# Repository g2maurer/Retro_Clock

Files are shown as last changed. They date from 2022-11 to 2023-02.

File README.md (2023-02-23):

# Retro_Clock
This is a highly modified version of TechKiwiGadgets clock found on 

1. Instructables     https://www.instructables.com/ESP32-Pacman-Clock/
2. Makerbot Thingiverse (ESP32 Pacman Clock)    https://www.thingiverse.com/thing:5136672

Modifications:
1. Changed TFT display to an SPI version which has a much improved Touch interface.
2. Added SPIFFS to support files for data and images. This freed up memory and added flexability.
3. Added support for optional RTC (real time clock IC). Improves time keeping accuracy.
4. Added support for LDR (light dependent resistor) so that display is dimmed at night.
5. Added audio amplifier (LM386) and volume control via touch screen.
6. Redesigned user interface (Touch menu) to support added features.
7. Made many changes to firmware to improve speed and readability. 
8. Designed PCB to support above mentioned changes.
9. Redesigned 3D printed parts to support hardware changes.

TFT_eSPI library:
1. The TFT_eSPI library requires it be changed to support each particular build (unusal but that's way way it works).
2. The file User_Setup_Select.h specifies which setup file in the User_Setups directory is to be used.
3. Added to the User_Setups directory is the file Setup_Pacman_Clock.h which contains the specifies the configuration and features (Touch) used by this project.
4. Move the file "Setup_Pacman_Clock.h" into directory   ...Arduino/libraries/TFT_eSPI/User_Setups
5. Move the file "User_Setup_Select.h" into the directory    ...Arduino/libraries/TFT_eSPI   (replaces the existing User_Setup_Select.h file). 

Tools:
1. Arduino IDE 1.8.19, Board: DOIT ESP32 DEVKIT V1
2. Initialize SPIFFS using Arduino IDE  "Tools/ESP32 Sketch Data Upload" (which will initializee SPIFFS and upload all the files from the Data directory).
3. Creality Slicer, PLA, 0.2mm, no supports.

Additional Notes:
1. 	Arduino Sketch (IDE) Version 1.8.19
2.	Board Manager -> esp32 by Espressif Systems Version 1.0.6
3.	Libraries used:

		TFT_eSPI at version 2.5.0
		RTClib at version 2.1.1
		Wire at version 1.0.1
		SPIFFS at version 1.0
		FS at version 1.0
		XT_DAC_Audio
		Time at version 1.6.1
		Adafruit_BusIO at version 1.14.1
4.	TFT_eSPI setup file contains (see TFT_eSPI folder in Arduino/libraries):

		#define USER_SETUP_ID 900
		#define ILI9341_DRIVER
		#define TFT_MISO	19
		#define TFT_MOSI	23
		#define TFT_SCLK	18
		#define TFT_CS		15
		#define TFT_DC		4
		#define TFT_RST		2

		#define TOUCH_CS	5		// Required to enable Touch, getTouch()

		#define LOAD_GLCD
		#define LOAD_FONT2
		#define LOAD_FONT4
		#define LOAD FONT6
		#define LOAD_FONT7
		#define LOAD_FONT8
		#define LOAD_GFXFF
		#define SMOOTH_FONT

		#define SPI_FREQUENCY 27000000					// 27 MHz
		#define SPI_READ_FREQUENCY 20000000				// 20 MHz
		#define SPI_TOUCH_FREQUENCY 2500000				// 2.5 MHz

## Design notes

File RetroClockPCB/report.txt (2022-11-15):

Plot file "C:\Users\Gerald\Documents\KiCad Projects\PacmanClock_ESP32_SPI_v1_1\PacmanClock_ESP32_SPI_v1_1-F_Cu.gbr" created.
Plot file "C:\Users\Gerald\Documents\KiCad Projects\PacmanClock_ESP32_SPI_v1_1\PacmanClock_ESP32_SPI_v1_1-B_Cu.gbr" created.
Plot file "C:\Users\Gerald\Documents\KiCad Projects\PacmanClock_ESP32_SPI_v1_1\PacmanClock_ESP32_SPI_v1_1-Edge_Cuts.gbr" created.
Create Gerber job file "C:\Users\Gerald\Documents\KiCad Projects\PacmanClock_ESP32_SPI_v1_1\PacmanClock_ESP32_SPI_v1_1-job.gbrjob"

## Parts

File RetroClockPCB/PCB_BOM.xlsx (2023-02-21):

Source: | C:\Users\gmaur\Documents\KiCad Projects\PacmanClock_ESP32_SPI_v1_3\PacmanClock_ESP32_SPI_v1_3.sch
Date: | 2023-02-21 08:52
Tool: | Eeschema (5.1.10)-1
Component Count: | 39
Ref | Value | Footprint | Notes | Datasheet | Manufacturer | Vendor
BT1 | LIR2032 | ESP32-footprints-Lib:BatteryHolder_Keystone_103_1x20mm_gm | LIR2032 3.7V Rechargable Battery | ~
C1 | 100nF | Capacitor_SMD:C_0805_2012Metric_Pad1.18x1.45mm_HandSolder |  | ~
C2 | 1uF | Capacitor_SMD:C_0805_2012Metric_Pad1.18x1.45mm_HandSolder |  | ~
C3 | 1000uF |  |  | ~
C4 | 1uF | Capacitor_SMD:C_0805_2012Metric_Pad1.18x1.45mm_HandSolder |  | ~
C5 | 10uF |  |  | ~
C6 | 47nF | Capacitor_SMD:C_0805_2012Metric_Pad1.18x1.45mm_HandSolder |  | ~
C7 | 479uF |  |  | ~
C8 | 100nF | Capacitor_SMD:C_0805_2012Metric_Pad1.18x1.45mm_HandSolder |  | ~
D1 | 1N4148W | Diode_SMD:D_SOD-123 |  | https://www.vishay.com/docs/85748/1n4148w.pdf
H1 | MountingHole | MountingHole:MountingHole_2.7mm_M2.5_DIN965 |  | ~
H2 | MountingHole | MountingHole:MountingHole_2.7mm_M2.5_DIN965 |  | ~
H3 | MountingHole | MountingHole:MountingHole_2.7mm_M2.5_DIN965 |  | ~
H4 | MountingHole | MountingHole:MountingHole_2.7mm_M2.5_DIN965 |  | ~
H5 | MountingHole | MountingHole:MountingHole_2.7mm_M2.5_DIN965 |  | ~
H6 | MountingHole | MountingHole:MountingHole_2.7mm_M2.5_DIN965 |  | ~
H7 | MountingHole | MountingHole:MountingHole_2.7mm_M2.5_DIN965 |  | ~
H8 | MountingHole | MountingHole:MountingHole_2.7mm_M2.5_DIN965 |  | ~
J1 | TFT | Connector_PinSocket_2.54mm:PinSocket_1x14_P2.54mm_Vertical |  | ~
J2 | Power | Connector_JST:JST_XH_B4B-XH-A_1x04_P2.50mm_Vertical |  | ~
J3 | Speaker | Connector_JST:JST_XH_B2B-XH-A_1x02_P2.50mm_Vertical |  | ~
J4 | LDR | Connector_JST:JST_XH_B2B-XH-A_1x02_P2.50mm_Vertical |  | ~
Q1 | 2N7000 | Package_TO_SOT_THT:TO-92 |  | ~
R1 | 20k | Resistor_SMD:R_0805_2012Metric_Pad1.20x1.40mm_HandSolder |  | ~
R2 | 0 | Resistor_SMD:R_0805_2012Metric_Pad1.20x1.40mm_HandSolder | Only install if not supporting LDR | ~
R3 | 1k | Resistor_SMD:R_0805_2012Metric_Pad1.20x1.40mm_HandSolder |  | ~
R4 | 10k | Resistor_SMD:R_0805_2012Metric_Pad1.20x1.40mm_HandSolder |  | ~
R5 | 10 | Resistor_SMD:R_0805_2012Metric_Pad1.20x1.40mm_HandSolder |  | ~
R6 | 4.7k | Resistor_SMD:R_0805_2012Metric_Pad1.20x1.40mm_HandSolder |  | ~
R7 | 10k | Resistor_SMD:R_0805_2012Metric_Pad1.20x1.40mm_HandSolder |  | ~
R8 | 10k | Resistor_SMD:R_0805_2012Metric_Pad1.20x1.40mm_HandSolder |  | ~
R9 | 4.7k | Resistor_SMD:R_0805_2012Metric_Pad1.20x1.40mm_HandSolder |  | ~
R10 | 10k | Resistor_SMD:R_0805_2012Metric_Pad1.20x1.40mm_HandSolder |  | ~
R11 | 4.7k | Resistor_SMD:R_0805_2012Metric_Pad1.20x1.40mm_HandSolder |  | ~
R12 | 200 | Resistor_SMD:R_0805_2012Metric_Pad1.20x1.40mm_HandSolder |  | ~
SW1 | Recal Touch | Tactile-switch:FSM2JRT_gm |  | ~
U1 | LM386 | Package_DIP:DIP-8_W7.62mm_LongPads |  | http://www.ti.com/lit/ds/symlink/lm386.pdf
U2 | ESP-WROOM-32S | ESP32-Footprints:ESP-WROOM-32S
U3 | DS3231M | Package_SO:SOIC-16W_7.5x10.3mm_P1.27mm |  | http://datasheets.maximintegrated.com/en/ds/DS3231.pdf
LDR | 5k | Light dependent resistor | Connected to J4
Speaker | 8 | 8 ohm speaker, 40mm | Connected to J3
TFT |  | 2.8 inch TFT with Touch, SPI interface | Connected to J1

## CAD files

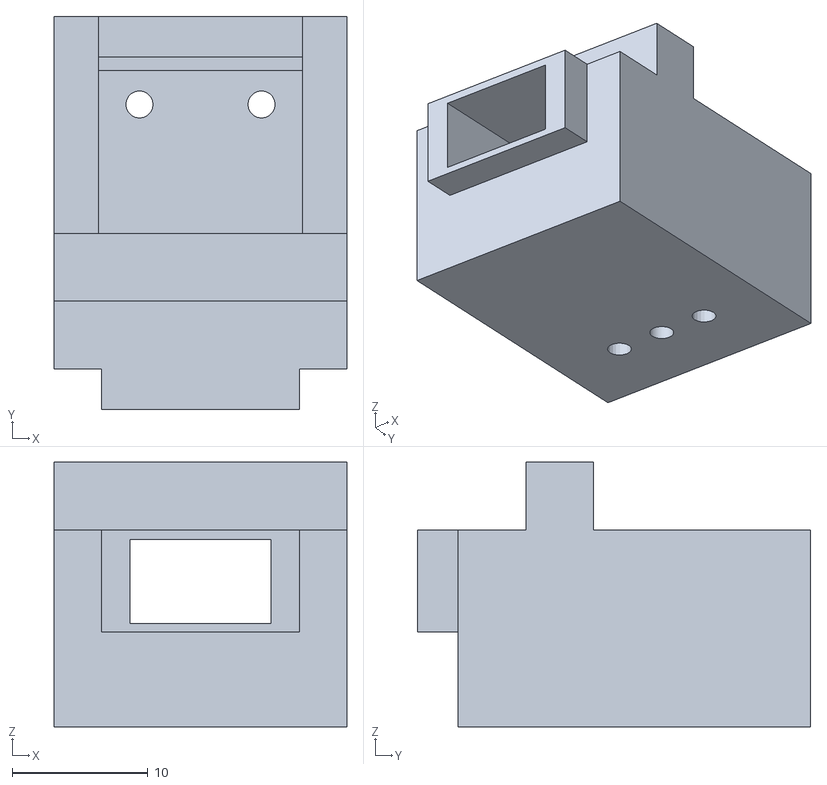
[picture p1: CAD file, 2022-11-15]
RetroClock_Case/MicroUSB2.stl
21.6 x 29.0 x 19.5

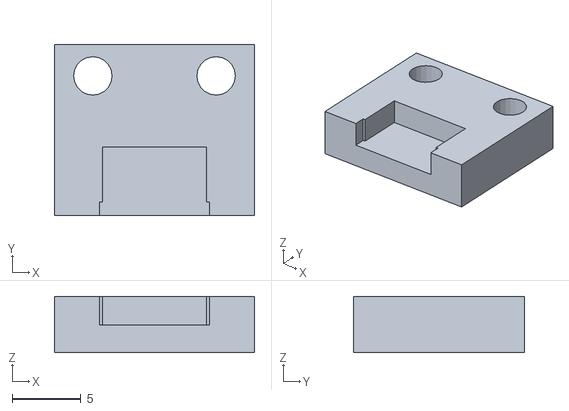
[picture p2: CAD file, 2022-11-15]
RetroClock_Case/USB_Lockdown.stl
14.6 x 12.5 x 4.10

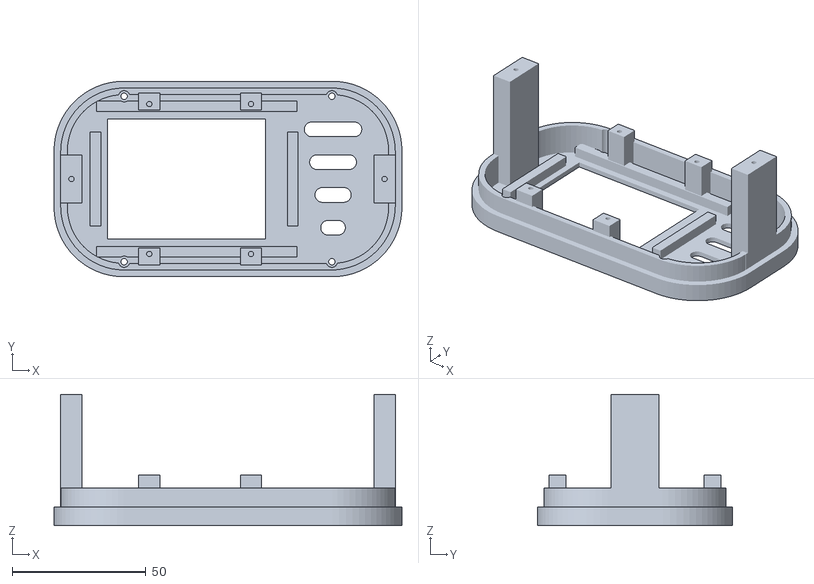
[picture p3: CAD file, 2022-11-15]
RetroClock_Case/ClockBezel.stl
130.0 x 73.0 x 49.0

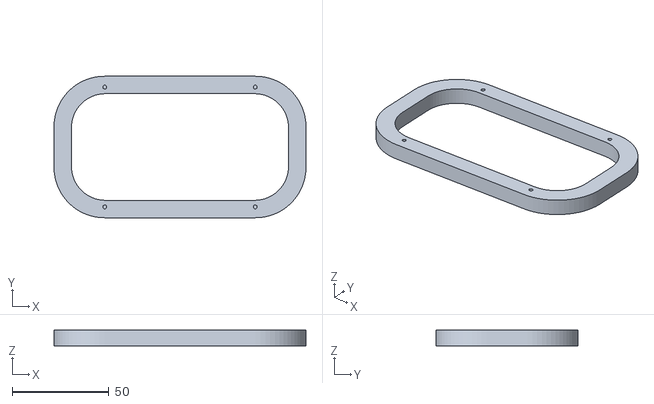
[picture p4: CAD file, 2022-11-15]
RetroClock_Case/BezelTrim.stl
130.0 x 73.0 x 8.00

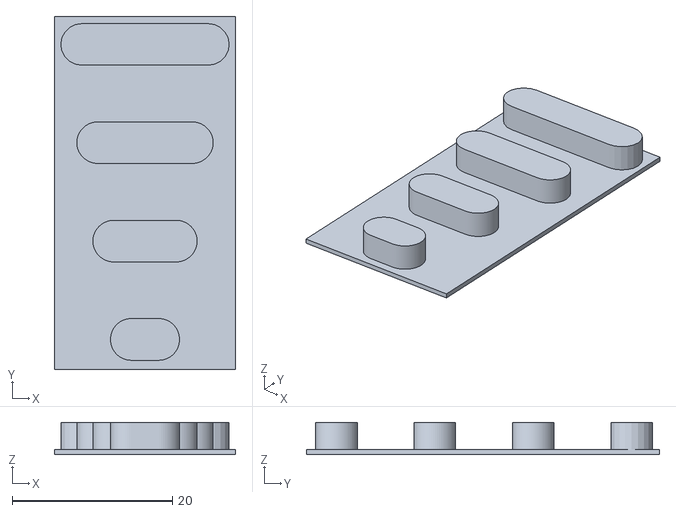
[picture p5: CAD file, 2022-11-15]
RetroClock_Case/BezelDecal.stl
22.6 x 44.0 x 4.00

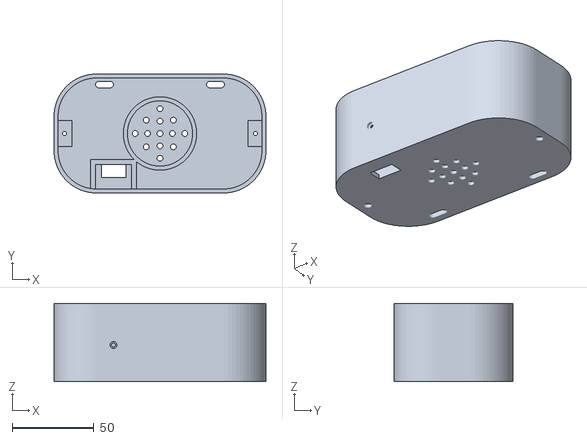
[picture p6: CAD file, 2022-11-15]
RetroClock_Case/ClockCase.stl
130.0 x 73.0 x 48.0

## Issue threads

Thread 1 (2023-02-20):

List of library used

Express1, 2023-02-20:
Can you please post the list of libraries/versions used to compile the project?

morganflint, 2023-02-21:
In my case, I followed the instructions [here](https://www.instructables.com/ESP32-Pacman-Clock/) for the parallel display software, step 6.1 (search "_Loading the correct Correct Libraries for the project!!_" ). Then, for g2maurer's SPI display software, followed the instructions in the readme.md of this repository, points 4 and 5 in the _TFT_eSPI_ library section.

g2maurer, 2023-02-24:
See github for update.

On Tue, Feb 21, 2023 at 3:29 AM morganflint ***@***.***>
wrote:

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

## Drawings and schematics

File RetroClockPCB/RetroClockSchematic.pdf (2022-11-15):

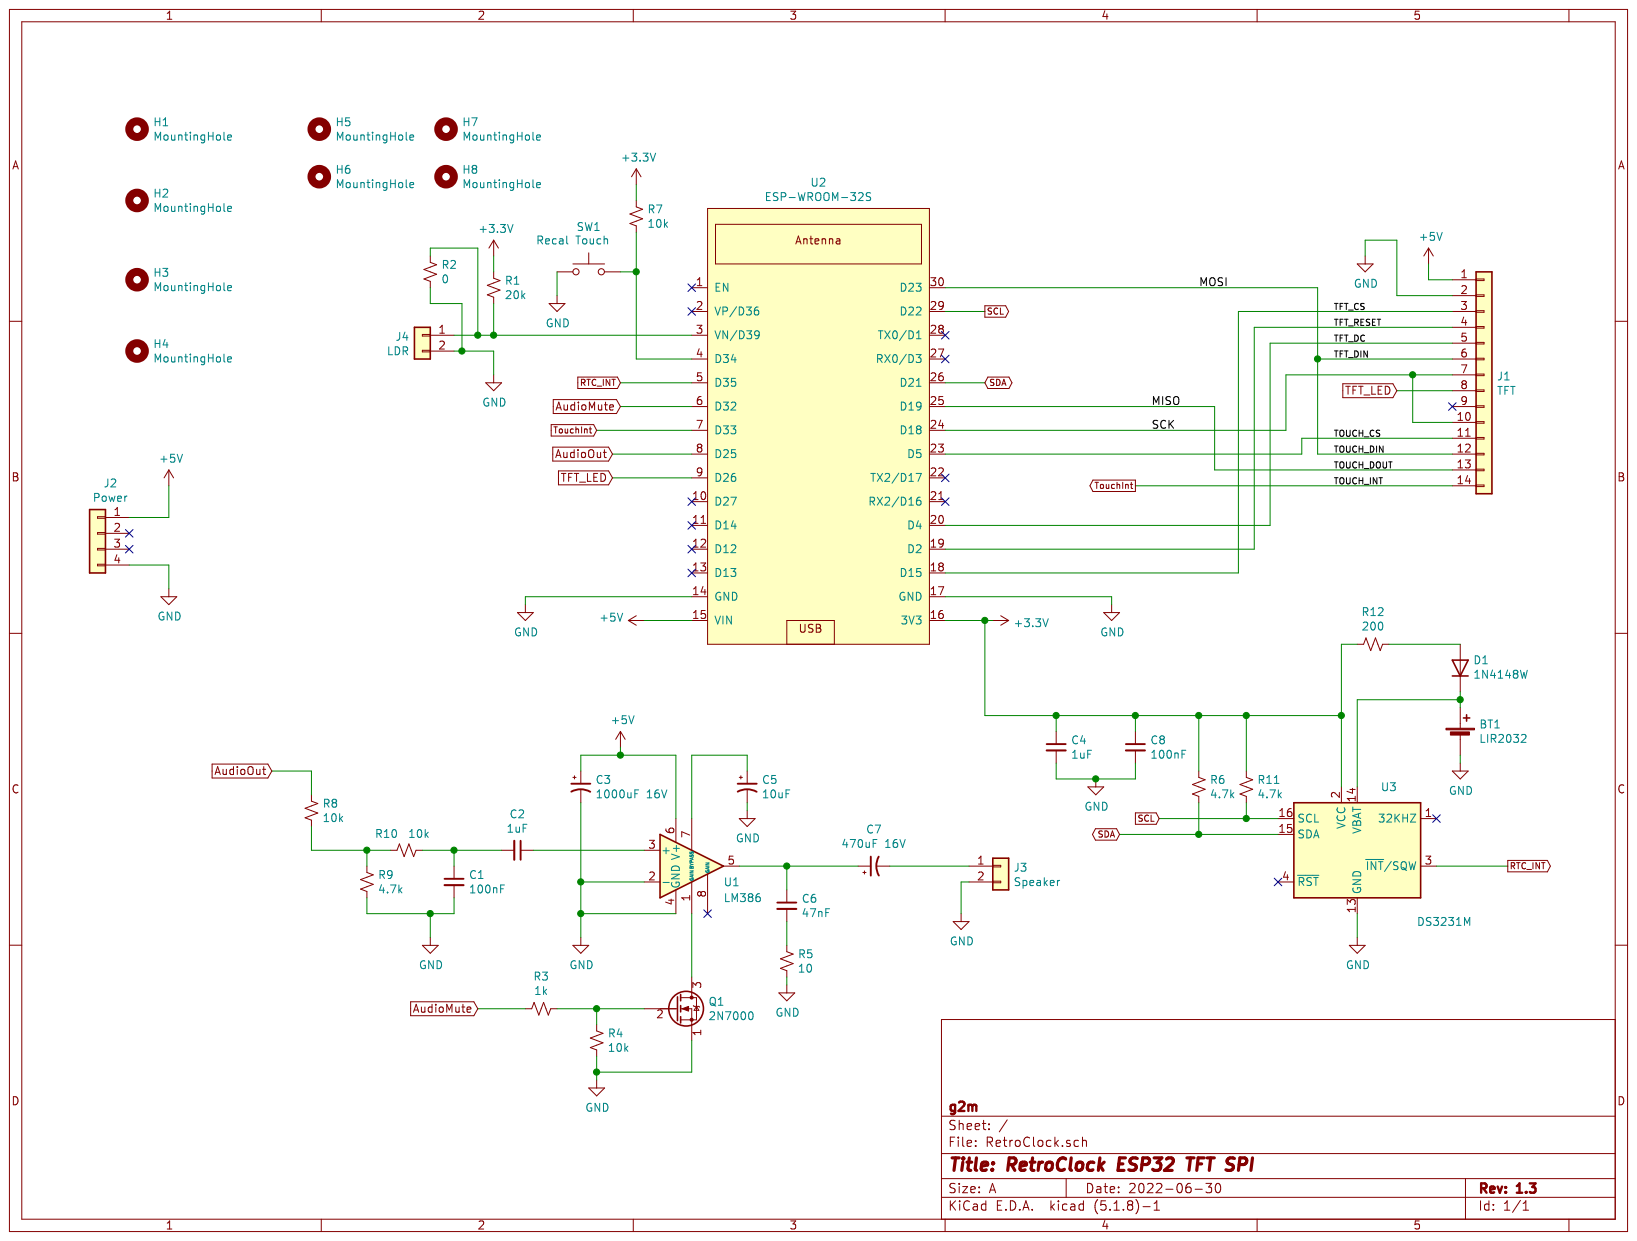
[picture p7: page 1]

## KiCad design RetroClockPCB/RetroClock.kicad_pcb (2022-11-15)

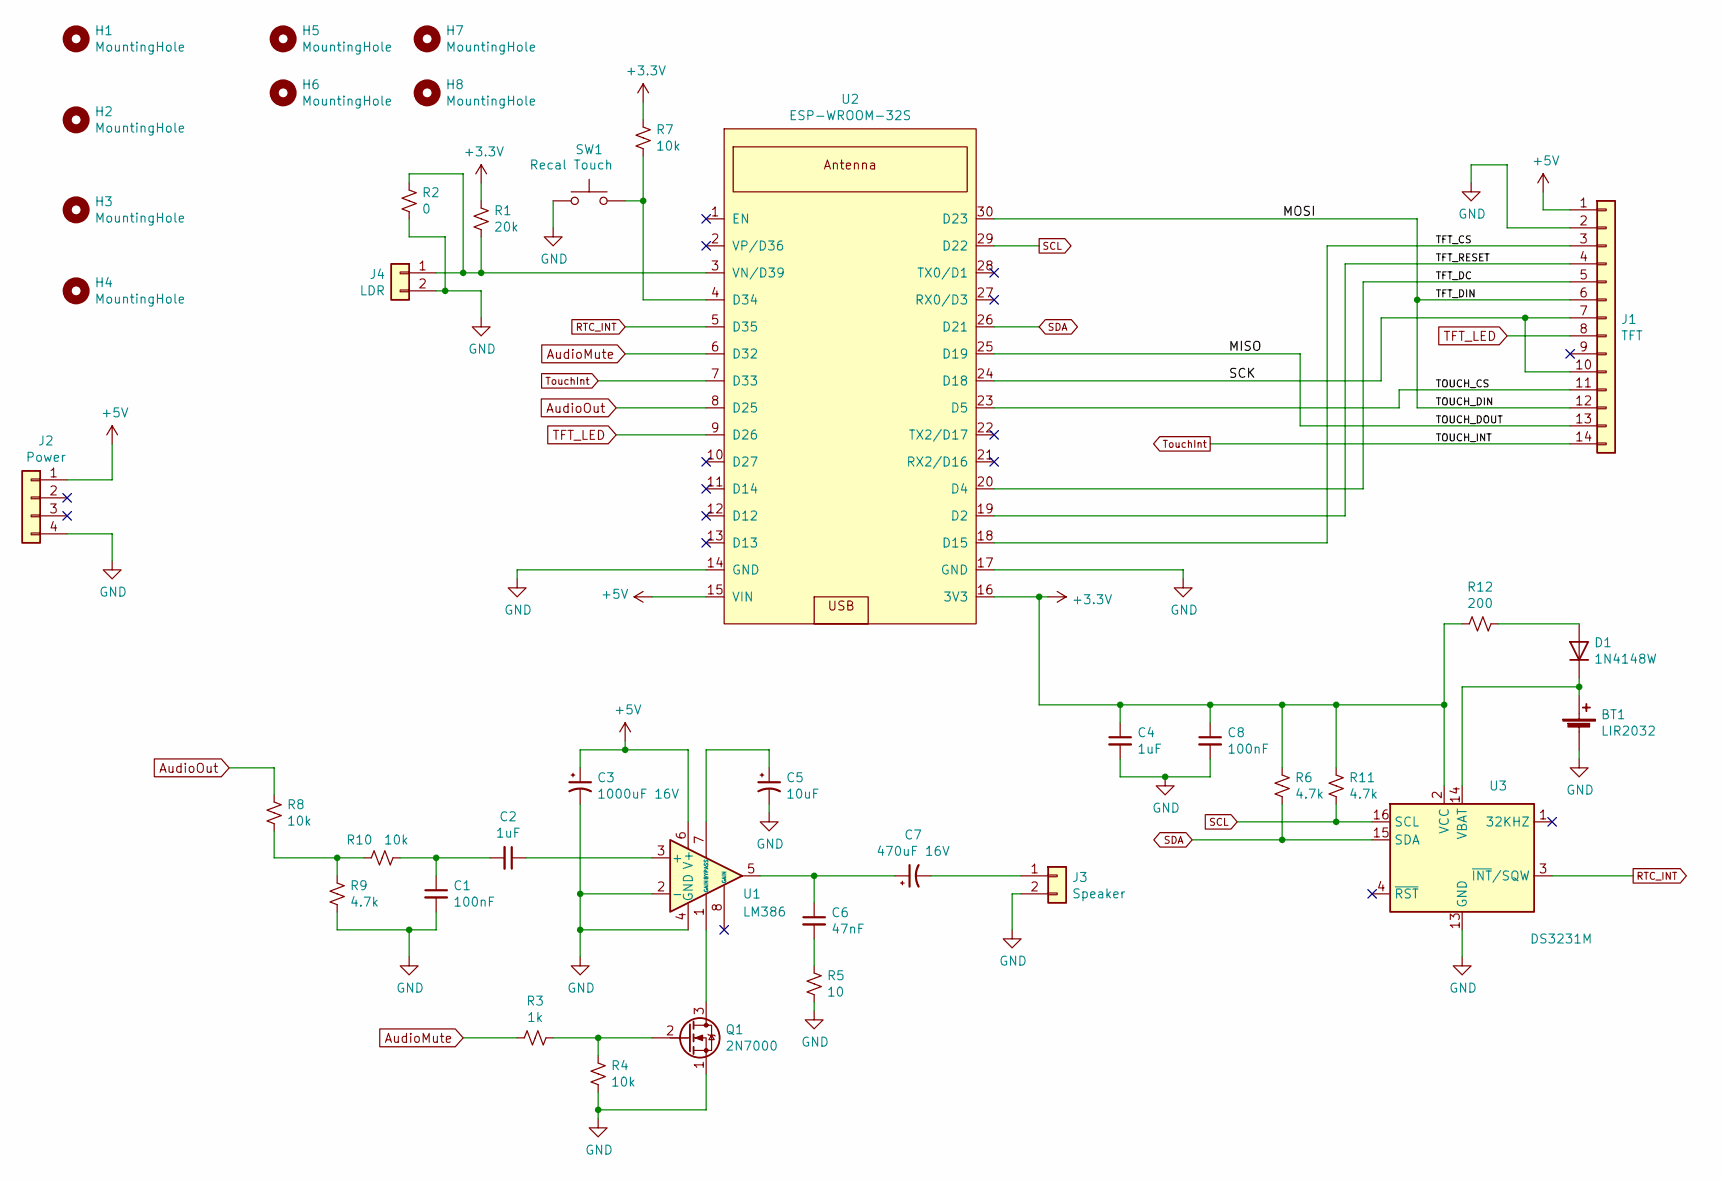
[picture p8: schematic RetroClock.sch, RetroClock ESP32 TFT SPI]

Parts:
BT1: LIR2032; BatteryHolder_Keystone_103_1x20mm_gm
C1, C8: 100nF; C_0805_2012Metric_Pad1.18x1.45mm_HandSolder
C2, C4: 1uF; C_0805_2012Metric_Pad1.18x1.45mm_HandSolder
C3: 1000uF 16V; CP_Radial_Tantal_D8.0mm_P2.50mm
C5: 10uF; CP_Radial_Tantal_D4.5mm_P5.00mm
C6: 47nF; C_0805_2012Metric_Pad1.18x1.45mm_HandSolder
C7: 470uF 16V; CP_Radial_Tantal_D8.0mm_P2.50mm
D1: 1N4148W; D_SOD-123
H1, H2, H3, H4, H5, H6, H7, H8: MountingHole; MountingHole_2.7mm_M2.5_DIN965
J1: TFT; PinSocket_1x14_P2.54mm_Vertical
J2: Power; JST_XH_B4B-XH-A_1x04_P2.50mm_Vertical
J3: Speaker; JST_XH_B2B-XH-A_1x02_P2.50mm_Vertical
J4: LDR; JST_XH_B2B-XH-A_1x02_P2.50mm_Vertical
Q1: 2N7000; TO-92
R1: 20k; R_0805_2012Metric_Pad1.20x1.40mm_HandSolder
R2: 0; R_0805_2012Metric_Pad1.20x1.40mm_HandSolder
R3: 1k; R_0805_2012Metric_Pad1.20x1.40mm_HandSolder
R4, R7, R8, R10: 10k; R_0805_2012Metric_Pad1.20x1.40mm_HandSolder
R5: 10; R_0805_2012Metric_Pad1.20x1.40mm_HandSolder
R6, R9, R11: 4.7k; R_0805_2012Metric_Pad1.20x1.40mm_HandSolder
R12: 200; R_0805_2012Metric_Pad1.20x1.40mm_HandSolder
SW1: Recal Touch; FSM2JRT_gm
U1: LM386; DIP-8_W7.62mm_LongPads
U2: ESP-WROOM-32S
U3: DS3231M; SOIC-16W_7.5x10.3mm_P1.27mm

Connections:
+3V3: C4.1, C8.1, R1.1, R6.1, R7.1, R11.1, R12.2, U2.16 (3V3), U3.2 (VCC)
+5V: C3.1, J1.1, J2.1, U1.6 (V+), U2.15 (VIN)
/MISO: J1.13, U2.25 (D19)
/MOSI: J1.6, J1.12, U2.30 (D23)
/SCK: J1.7, J1.10, U2.24 (D18)
/TFT_CS: J1.3, U2.18 (D15)
/TFT_DC: J1.5, U2.20 (D4)
/TFT_RESET: J1.4, U2.19 (D2)
/TOUCH_CS: J1.11, U2.23 (D5)
AudioMute: R3.2, U2.6 (D32)
AudioOut: R8.1, U2.8 (D25)
GND: BT1.2 (-), C1.2, C3.2, C4.2, C5.2, C8.2, J1.2, J2.4, J3.2, J4.2, Q1.1 (S), R2.2, R4.2, R5.2, R9.2, SW1.1, U1.2 (-), U1.4 (GND), U2.14 (GND), U2.17 (GND), U3.5 (GND), U3.6 (GND), U3.7 (GND), U3.8 (GND), U3.9 (GND), U3.10 (GND), U3.11 (GND), U3.12 (GND), U3.13 (GND)
unnamed: BT1.1 (+), D1.1 (K), U3.14 (VBAT)
unnamed: C1.1, C2.2, R10.2
unnamed: C2.1, U1.3 (+)
unnamed: C5.1, U1.7 (BYPASS)
unnamed: C6.1, C7.1, U1.5
unnamed: C6.2, R5.1
unnamed: C7.2, J3.1
unnamed: D1.2 (A), R12.1
unnamed: J4.1, R1.2, R2.1, U2.3 (VN/D39)
unnamed: Q1.2 (G), R3.1, R4.1
unnamed: Q1.3 (D), U1.1 (GAIN)
unnamed: R7.2, SW1.2, U2.4 (D34)
unnamed: R8.2, R9.1, R10.1
RTC_INT: U2.5 (D35), U3.3 (~INT~/SQW)
SCL: R11.2, U2.29 (D22), U3.16 (SCL)
SDA: R6.2, U2.26 (D21), U3.15 (SDA)
TFT_LED: J1.8, U2.9 (D26)
TouchInt: J1.14, U2.7 (D33)

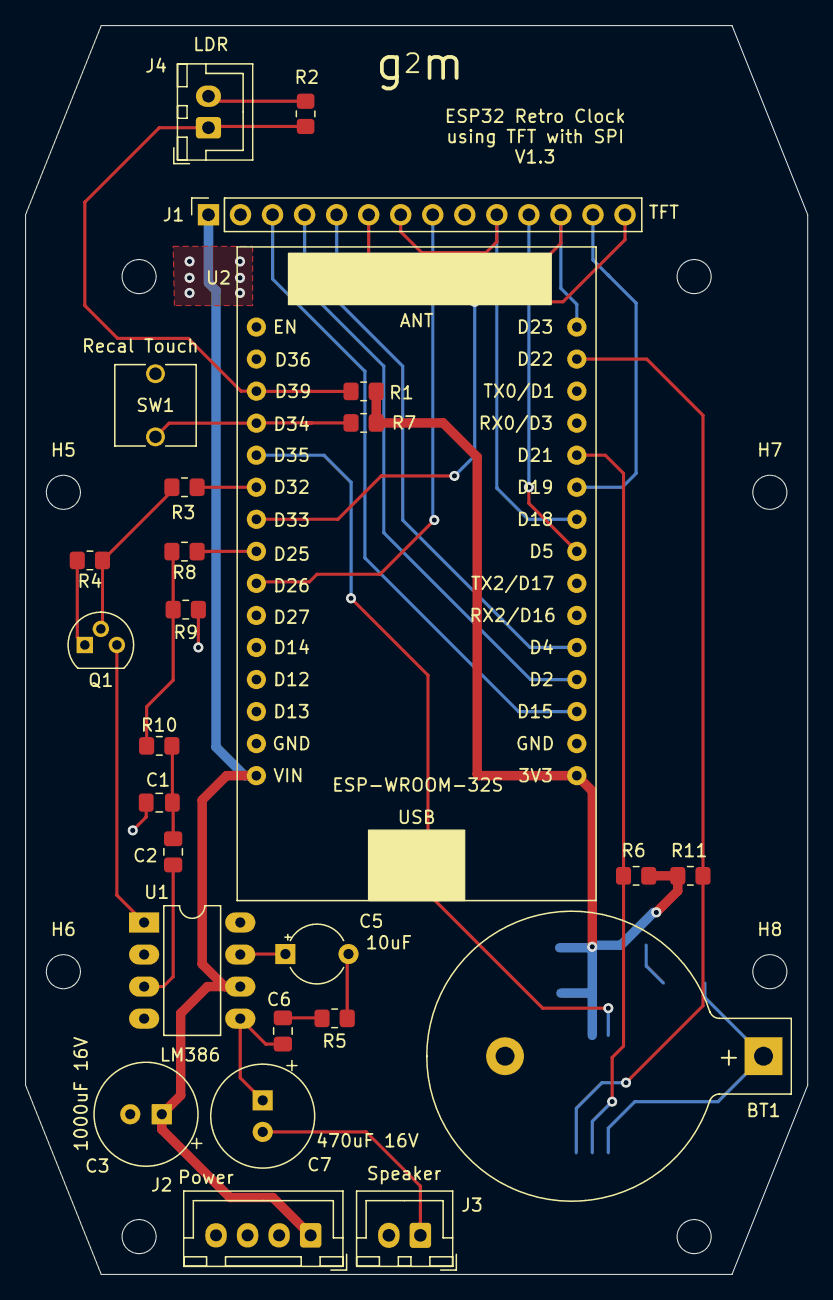
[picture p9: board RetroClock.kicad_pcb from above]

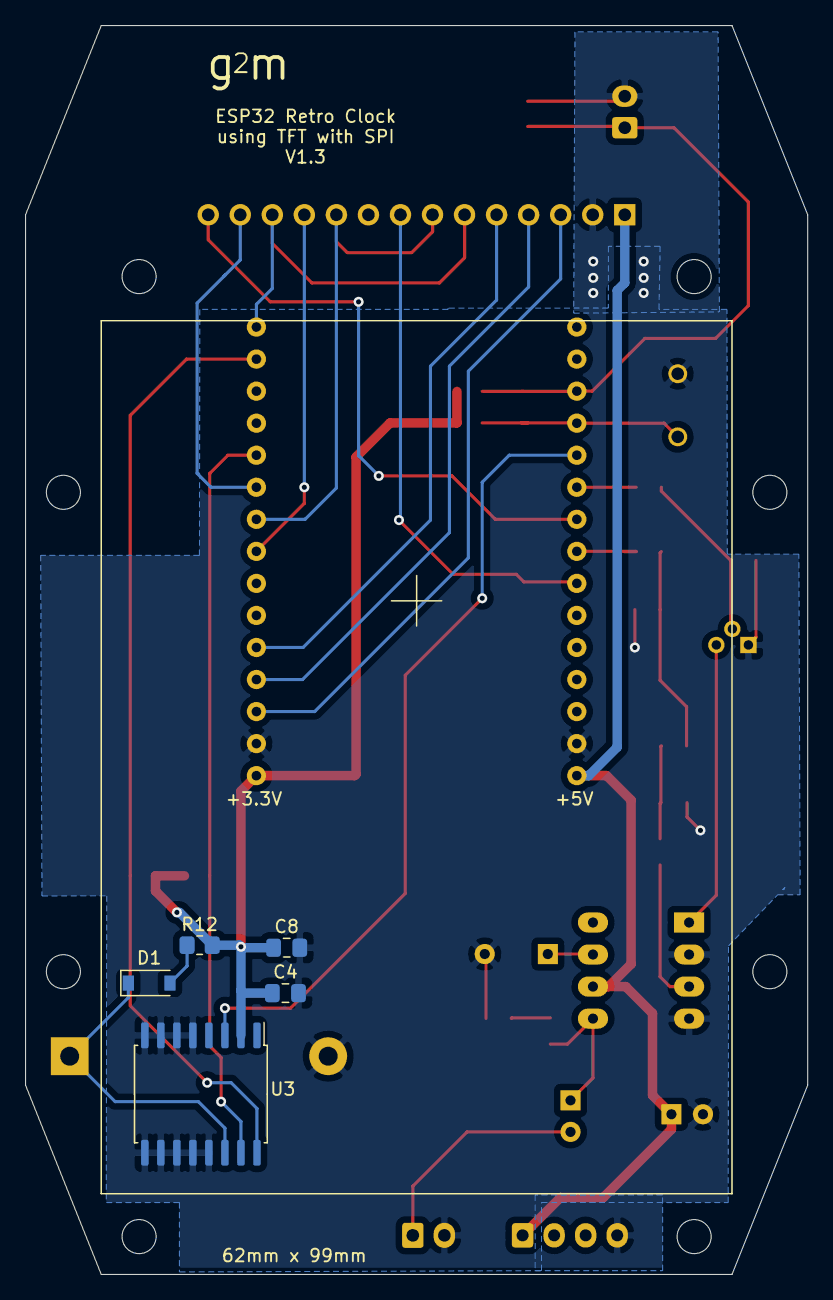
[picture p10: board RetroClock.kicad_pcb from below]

Board: 2 copper layers, 62.0 x 99.0 mm, 39 parts (5 on the bottom side), 30 nets.

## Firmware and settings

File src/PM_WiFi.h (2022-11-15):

//#include <WiFi.h>

#define DEBUG_WIFI
#ifdef DEBUG_WIFI
#define WIFI_PRINT(x) Serial.print(x)
#define WIFI_PRINTLN(x) Serial.println(x)
#define WIFI_PRINTF(x,y) Serial.printf(x,y)
#else
#define WIFI_PRINT(x)
#define WIFI_PRINTLN(x)
#define WIFI_PRINTF(x,y)
#endif

#define DEFAULT_SSID "ssid"
#define DEFAULT_PASSWORD "password"

const char* hostName = "Pac-manClock";

//GMT Time Zone with sign
#define GMT_TIME_ZONE -8

struct WIFI_CONFIG_STRUCT {
  char ssID[32];
  char passWord[32];
} WiFiConfig;


#define MAX_NETWORK_CNT 8

struct WIFI_INFO_STRUCT {
  char  localIP[20];
  char  subnetMask[20];
  char  gatewayIP[20];
  char  macAddress[20];
} WiFiInfo;

struct SSID_Struct {
  char ssid[64];
  int rssi;
  int encryptType;
};
struct NETWORK_Struct {
  int count;
  SSID_Struct Tbl[MAX_NETWORK_CNT+2];
} WifiNetworks;



void init_WiFi(void);
void connectWiFi(void);
void disconnectWiFi(void);
String  statusWiFi(void);
int getWiFiQuality(void);

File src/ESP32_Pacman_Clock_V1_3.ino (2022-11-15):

/*  Retro Pac-Man Clock
  Author: @TechKiwiGadgets Date 08/04/2017

  Licensed as Attribution-NonCommercial-ShareAlike 4.0 International (CC BY-NC-SA 4.0)
  You are free to:
  Share — copy and redistribute the material in any medium or format
  Adapt — remix, transform, and build upon the material
  Under the following terms:
  Attribution — You must give appropriate credit, provide a link to the license, and indicate if changes were made. You may do so in any reasonable manner, but not in any way that suggests the licensor endorses you or your use.
  NonCommercial — You may not use the material for commercial purposes.
  ShareAlike — If you remix, transform, or build upon the material, you must distribute your contributions under the same license as the original

  V67 First Instructables release
*/

#define TFT_SPI           // uncomment if using TFT display with SPI interface
#define LM386_AUDIO
//#define DS3231_RTC

//
//  If Sprite library worked correctly and we used sprites for the Ghost and Pacman
//  we wouldn't have to redraw the dots after the Ghost passed over them.
//
//#define SPRITE        // Sprite library doesn't seem to work correctly.

//
//  The following are for debugging
//    uncomment the '#define' to get debug prints.
//

//#define DEBUG_PACMAN
#ifdef DEBUG_PACMAN
#define PACMAN_PRINT(x) Serial.print(x)
#define PACMAN_PRINTLN(x) Serial.println(x)
#define PACMAN_PRINTF(x,y) Serial.printf(x,y)
#else
#define PACMAN_PRINT(x)
#define PACMAN_PRINTLN(x)
#define PACMAN_PRINTF(x,y)
#endif

//#define DEBUG_CONFIG
#ifdef DEBUG_CONFIG
#define CONFIG_PRINT(x) Serial.print(x)
#define CONFIG_PRINTLN(x) Serial.println(x)
#define CONFIG_PRINTF(x,y) Serial.printf(x,y)
#else
#define CONFIG_PRINT(x)
#define CONFIG_PRINTLN(x)
#define CONFIG_PRINTF(x,y)
#endif

#include "PM_SPIFFS.h"
#include "PM_WiFi.h"
#include "PM_TFT.h"


#include <Arduino.h>
#ifndef DS3231_RTC
#include <WiFi.h>
#include <NTPClient.h>
#endif
#include "XT_DAC_Audio.h"
#include "TFT_eSPI.h"
#include <TimeLib.h>
#include <pgmspace.h>

#ifdef DS3231_RTC
#include "PM_RTC_NTP.h"
#endif



#ifndef TFT_SPI
#include <TouchScreen.h>
#endif

#include "Free_Fonts.h"
#include "SoundData.h"

IPAddress localIP;

#define SCREENWIDTH 320
#define SCREENHEIGHT 240

#ifndef TFT_SPI   // not TFT_SPI
#define YP 14  // must be an analog pin, use "An" notation!
#define XM 27  // must be an analog pin, use "An" notation!
#define YM 4   // can be a digital pin
#define XP 16  // can be a digital pin
#define MAXPRESSURE 799

// Enter Callibration Variables here for the touch screen
// Run callibration sketch first then write down the following coordicates and update sketch

TouchScreen ts = TouchScreen(XP, YP, XM, YM, 300);

boolean debounce = false;

#endif    // not TFT_SPI

//
//  ESP32 pin definitions
//

//
//  AUDIO pins
//
#define MUTE_PIN  32
#ifdef LM386_AUDIO
// using LM386 audio amplifier
#define MUTE  HIGH
#define UNMUTE  LOW
#else
// original uses HW-104 audio amplifier board
#define MUTE  LOW
#define UNMUTE  HIGH
#endif
#define AUDIO_OUT_PIN 25


unsigned long mlStart = 0;
unsigned long mlEnd = 0;


//
//  TFT Brightness Control pins
//
#ifdef TFT_SPI
// SPI TFT ONLY !!!
#define TFT_LED 26      // TFT LED control pin
#define LDR_PIN 39      // Light dependent resistor
int dutyCycle = 255;    // TFT LED dutycycle
#endif

#define LDR_CHECK_TIME_PERIOD 3000    // three seconds
unsigned long timePeriodStart = 0;

//
//  SPIFFS files
//   File names (fn.....)
//
const char* fnTftCal = "/tftcal.bin";
const char* fnWifiConfig = "/wifi.bin";
const char* fnClockConfig = "/config.bin";
const char* fnTimeZoneConfig = "/timezone.bin";
const char* fnBlueGhost = "/blueGhost.bin";
const char* fnRedGhostLeft = "/redGhostL.bin";
const char* fnRedGhostRight = "/redGhostR.bin";
const char* fnRedGhostUp = "/redGhostU.bin";
const char* fnRedGhostDown = "/redGhostD.bin";
const char* fnFruit = "/fruit.bin";
const char* fnPacClosed = "/pacClosed.bin";
const char* fnPacHalf = "/pacHalf.bin";
const char* fnPacOpen = "/pacOpen.bin";
const char* fnMsPacClosed = "/mPacClosed.bin";
const char* fnMsPacHalf = "/mPacHalf.bin";
const char* fnMsPacOpen = "/mPacOpen.bin";


//
//  NTP - Network Time Protocol
//
//const char* TZ_INFO = "NZST-12NZDT-13,M9.4.0/02:00:00,M4.1.0/03:00:00";
//const char* TZ_INFO = "PST8PDT,M3.2.0,M11.1.0";   //"PST8PDT";
//const char* ntpServer1 = "uk.pool.ntp.org";

const char* ntpServer1 = "time.nist.gov";
const char* ntpServer2 = "ptbtime1.ptb.de";
const char* ntpServer3 = "pool.ntp.org";

//
//  Clock Variables
//
byte clockhour; // Holds current hour value
byte clockminute; // Holds current minute value


//
// Alarm Variables
//
boolean soundalarm = false; // Flag to indicate the alarm needs to be initiated
int actr = 3000; // When alarm sounds this is a counter used to reset sound card until screen touched
int act = 0;

//
//  Pac-man Clock Configuration data, saved in SPIFFS, restored on boot/reboot
//
struct CLOCK_CONFIG_STRUCT {
  int pad1;
  boolean alarmStatus;
  int alarmHour;  // hour of alarm setting
  int alarmMinute; // Minute of alarm setting
  int speedSetting;
  int alarmVolume;
  boolean mspacman;
  boolean clock24;
  boolean celsiusFlag;
  int pad3;
} clockConfig;

//
//Dot Array - There are 72 Dots with 4 of them that will turn Ghost Blue!
//
typedef struct DOT_STRUCT {
  bool state;    // true or false, if false it has been gobbled by Pac-Man
  short xPos;
  short yPos;
  byte dotSize;     // small = 2, large = 7
} DOT;


//
//    Dot location Array
//        [state, x, y, size]
//
DOT dots[73] = {
  {0, 0, 0, 0},       // NOT USED
  {true, 19, 19, 2},  // dot 1, Row 1
  {true, 42, 19, 2},
  {true, 65, 19, 2},
  {true, 88, 19, 2},
  {true, 112, 19, 2},
  {true, 136, 19, 2},
  {true, 183, 19, 2},
  {true, 206, 19, 2},
  {true, 229, 19, 2},
  {true, 252, 19, 2}, // dot 10
  {true, 275, 19, 2},
  {true, 298, 19, 2},
  {true, 19, 40, 7},  // dot 13, Row 2  BIG DOT
  {true, 77, 40, 2},
  {true, 136, 40, 2},
  {true, 183, 40, 2},
  {true, 241, 40, 2},
  {true, 298, 40, 7}, // BIG DOT
  {true, 19, 60, 2},  // dot 19, Row 3
  {true, 42, 60, 2},  // dot 20
  {true, 65, 60, 2},
  {true, 88, 60, 2},
  {true, 112, 60, 2},
  {true, 136, 60, 2},
  {true, 160, 60, 2},
  {true, 183, 60, 2},
  {true, 206, 60, 2},
  {true, 229, 60, 2},
  {true, 252, 60, 2},
  {true, 275, 60, 2}, // dot 30
  {true, 298, 60, 2},
  {true, 42, 80, 2},  // dot 32, Row 4
  {true, 275, 80, 2},
  {true, 42, 100, 2}, // dot 34, Row 5
  {true, 275, 100, 2},
  {true, 42, 120, 2}, // dot 36, Row 6
  {true, 275, 120, 2},
  {true, 42, 140, 2}, // dot 38, Row 7
  {true, 275, 140, 2},
  {true, 42, 160, 2}, // dot 40, Row 8
  {true, 275, 160, 2},
  {true, 19, 181, 2}, // dot 42, Row 9
  {true, 42, 181, 2},
  {true, 65, 181, 2},
  {true, 88, 181, 2},
  {true, 112, 181, 2},
  {true, 136, 181, 2},
  {true, 160, 181, 2},
  {true, 183, 181, 2},
  {true, 206, 181, 2},  // dot 50
  {true, 229, 181, 2},
  {true, 252, 181, 2},
  {true, 275, 181, 2},
  {true, 298, 181, 2},
  {true, 19, 201, 7}, // dot 55, Row 10  BIG DOT
  {true, 77, 201, 2},
  {true, 136, 201, 2},
  {true, 183, 201, 2},
  {true, 241, 201, 2},
  {true, 298, 201, 7},  // dot 60  BIG DOT
  {true, 19, 221, 2}, // dot 61, Row 11
  {true, 42, 221, 2},
  {true, 65, 221, 2},
  {true, 88, 221, 2},
  {true, 112, 221, 2},
  {true, 136, 221, 2},
  {true, 183, 221, 2},
  {true, 206, 221, 2},
  {true, 229, 221, 2},
  {true, 252, 221, 2},  // dot 70
  {true, 275, 221, 2},
  {true, 298, 221, 2}
};

//
//  Define the number of Dots in each Row
//
#define DOTS_IN_ROW_1   12
#define DOTS_IN_ROW_2   6
#define DOTS_IN_ROW_3   13
#define DOTS_IN_ROW_4   13
#define DOTS_IN_ROW_5   6
#define DOTS_IN_ROW_6   12

//
//  x axis position for Dots (by Row)
//
short row1n6dots[DOTS_IN_ROW_1] = {4, 28, 52, 74, 98, 120, 168, 192, 216, 238, 262, 284};       // rows 1 & 6
short row2n5dots[DOTS_IN_ROW_2] = {4, 62, 120, 168, 228, 284};                                  // rows 2 & 5
short row3n4dots[DOTS_IN_ROW_3] = {4, 28, 52, 74, 98, 120, 146, 168, 192, 216, 238, 262, 284};  // rows 3 & 4

//
//  Adjacent Dot Lookup Table
//
byte adjacentDots[73][4] = {
  {0, 0, 0, 0},
  {2, 13, 0, 0},    //dot 1, Row 1
  {1, 3, 0, 0},   //dot 2
  {2, 4, 14, 0},    //dot 3
  {3, 5, 14, 0},    //dot 4
  {4, 6, 0, 0},   //dot 5
  {5, 15, 0, 0},    //dot 6
  {8, 16, 0, 0},    //dot 7
  {7, 9, 0, 0},   //dot 8
  {8, 10, 17, 0},   //dot 9
  {9, 11, 17, 0},   //dot 10
  {10, 12, 18, 0},  //dot 11
  {11, 18, 0, 0},   //dot 12
  {1, 19, 0, 0},    //dot 13, Row 2  BIG DOT
  {3, 4, 21, 22},   //dot 14
  {6, 24, 0, 0},    //dot 15
  {7, 26, 0, 0},    //dot 16
  {9, 10, 28, 29},   //dot 17
  {12, 31, 0, 0},   //dot 18  BIG DOT
  {13, 20, 0, 0},   //dot 19, Row 3
  {13, 19, 21, 32}, //dot 20
  {14, 20, 22, 0},  //dot 21
  {14, 21, 23, 0},  //dot 22
  {22, 24, 0, 0},   //dot 23
  {15, 23, 25, 0},  //dot 24
  {24, 26, 0, 0},   //dot 25
  {16, 25, 27, 0},  //dot 26
  {28, 26, 0, 0},   //dot 27
  {17, 27, 29, 0},  //dot 28
  {17, 28, 30, 0},  //dot 29
  {18, 29, 31, 33}, //dot 30
  {18, 30, 0, 0},   //dot 31, end of Row 3
  {20, 34, 0, 0},   //dot 32, column 2
  {30, 35, 0, 0},   //dot 33, column 7
  {32, 36, 0, 0},   //dot 34
  {33, 37, 0, 0},   //dot 35
  {34, 38, 0, 0},   //dot 36
  {35, 39, 0, 0},   //dot 37
  {36, 40, 0, 0},   //dot 38
  {37, 41, 0, 0},   //dot 39
  {38, 43, 0, 0},   //dot 40
  {39, 53, 0, 0},   //dot 41
  {43, 55, 0, 0},   //dot 42, Row 4
  {40, 42, 44, 0},  //dot 43
  {43, 45, 56, 0},  //dot 44
  {44, 46, 56, 0},  //dot 45
  {45, 47, 0, 0},   //dot 46
  {46, 48, 57, 0},  //dot 47
  {47, 49, 0, 0},   //dot 48
  {48, 50, 58, 0},  //dot 49
  {49, 51, 0, 0},   //dot 50
  {50, 52, 59, 0},  //dot 51
  {51, 53, 59, 0},  //dot 52
  {41, 52, 54, 60}, //dot 53
  {53, 60, 0, 0},   //dot 54
  {42, 61, 0, 0},   //dot 55, Row 5  BIG DOT
  {44, 45, 63, 63}, //dot 56
  {47, 66, 0, 0},   //dot 57
  {49, 67, 0, 0},   //dot 58
  {51, 52, 69, 70}, //dot 59
  {54, 72, 0, 0},   //dot 60  BIG DOT
  {55, 62, 0, 0},   //dot 61, Row 6
  {61, 63, 0, 0},   //dot 62
  {56, 62, 64, 0},  //dot 63
  {56, 63, 65, 0},  //dot 64
  {64, 66, 0, 0},   //dot 65
  {57, 65, 0, 0},   //dot 66
  {58, 68, 0, 0},   //dot 67
  {67, 69, 0, 0},   //dot 68
  {59, 68, 70, 0},  //dot 69
  {59, 69, 71, 0},  //dot 70
  {60, 70, 72, 0},  //dot 71
  {60, 71, 0, 0}    //dot 72
};

//
//  ICON definitions
//
#define ICON_SIZE 1568
#define DIR_RIGHT 0
#define DIR_DOWN 1
#define DIR_LEFT 2
#define DIR_UP 3
#define CLOSED_MOUTH 0
#define HALF_OPEN_MOUTH 1
#define OPEN_MOUTH 2

//
//  array of pointers to Pac-man / Ms Pac-man ICONs
//
unsigned short *ptrPacman[3][4];
//
//  array of pointers to Red Ghost ICONs
//
unsigned short *ptrGhost[4];

//
//  ICONs - loaded from SPIFFS (files)
//
unsigned short pacmanClosedRight[0x310];      // Pacman mouth closed facing right
unsigned short pacmanHalfOpenRight[0x310];    // Pacman mouth half open facing right
unsigned short pacmanOpenRight[0x310];        // Pacman mouth open facing right
unsigned short pacmanClosedDown[0x310];
unsigned short pacmanHalfOpenDown[0x310];
unsigned short pacmanOpenDown[0x310];
unsigned short pacmanClosedLeft[0x310];
unsigned short pacmanHalfOpenLeft[0x310];
unsigned short pacmanOpenLeft[0x310];
unsigned short pacmanClosedUp[0x310];
unsigned short pacmanHalfOpenUp[0x310];
unsigned short pacmanOpenUp[0x310];

unsigned short redGhostEyesRight[0x310];
unsigned short redGhostEyesDown[0x310];
unsigned short redGhostEyesLeft[0x310];
unsigned short redGhostEyesUp[0x310];
unsigned short blueGhost[0x310];
unsigned short fruitIcon[0x310];

//
//  Game variables
//
// Fruit flags
boolean fruitgone = false;
boolean fruitdrawn = false;
boolean fruiteatenpacman = false;
//Pacman & Ghost kill flags
boolean pacmanlost = false;
boolean ghostlost = false;

// Scorecard
int pacmanscore = 0;
int ghostscore = 0;

//int userspeedsetting = 1; // user can set normal, fast, crazy speed for the pacman animation

int gamespeed = 18; //22; // Delay setting in mS for game default is 18
int cstep = 2; // Provides the resolution of the movement for the Ghost and Pacman character. Origially set to 2

// Animation delay to slow movement down
int dly = gamespeed; // Orignally 30

//Alarm setup variables
boolean xsetup = false; // Flag to determine if exiting setup mode

// Time Refresh counter
int rfcvalue = 900; // wait this long until check time for changes
int rfc = 1;

//
// Graphics Drawing Variables
//

//
// Pac-man coordinates (top LHS of 28x28 bitmap)
//
int xP = 4;         // Pac-man x axis
int yP = 108;       // Pac-man y axis
int P = 0;  // Pacman Graphic Flag 0 = Closed, 1 = Medium Open, 2 = Wide Open, 3 = Medium Open
int D = 0;  // Pacman direction 0 = right, 1 = down, 2 = left, 3 = up
int prevD;  // Capture legacy direction to enable adequate blanking of trail
int direct;   //  Random direction variable

//
// Ghost coordinates  (top LHS of 28x28 bitmap)
//
int xG = 288;       // Ghost x axis
int yG = 108;       // Ghost y aXIS
int GD = 2;  // Ghost direction 0 = right, 1 = down, 2 = left, 3 = up
int prevGD;  // Capture legacy direction to enable adequate blanking of trail
int gdirect;   //  Random direction variable

//
// Declare global variables for previous time, to enable refesh of only digits that have changed
// There are four digits that need to be drawn independently to ensure consistent positioning of time
//
int c1 = 20;  // Tens hour digit
int c2 = 20;  // Ones hour digit
int c3 = 20;  // Tens minute digit
int c4 = 20;  // Ones minute digit

TFT_eSPI myGLCD = TFT_eSPI();       // Invoke custom library

const GFXfont *gfxFont = NULL;

//unsigned long runTime = 0;
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
void loop()
{
  //  mlStart = millis();
  setgamespeed(); // Set game animation speed
  printscoreboard(); //Print scoreboard
  drawfruit();  // Draw fruit and allocate points
  refreshgame(); // Read the current date and time from the RTC and reset board
  triggeralarm(); //=== Check if Alarm needs to be sounded
  mainuserinput(); // Check if user input to touch screen
  displaypacman(); // Draw Pacman in position on screen
  displayghost(); // Draw Ghost in position on screen
  //  mlEnd = millis();
  //  Serial.println(mlEnd-mlStart);
  delay(dly);
#ifdef TFT_SPI
  //
  //  Check LDR every "LDR_CHECK_TIME_PERIOD" for change in light
  //
  if (millis() - timePeriodStart > LDR_CHECK_TIME_PERIOD)
  {
    setLEDdutyCycle();
    timePeriodStart = millis();
  }
#endif
}

//////////////////////////////////////////////////////////
//
//  Set TFT backlight LED duty cycle (brightness)
//
#ifdef TFT_SPI
//
//  Sets the TFT backlight LED duty cycle
//    dims LED when room is dark.
//
void setLEDdutyCycle(void)
{
  int light = analogRead(LDR_PIN);
  PACMAN_PRINTLN(light);
  dutyCycle = (4095 - light) / 15;
  if (dutyCycle > 240) dutyCycle = 255;
  if (dutyCycle < 20) dutyCycle = 20;
  PACMAN_PRINT(dutyCycle);
  PACMAN_PRINTLN(" = Backlight LED dutycycle");
  ledcWrite(0, dutyCycle);
}
#endif

///////////////////////////////////////////////////////////
//
//
//
void setgamespeed() {

  if (clockConfig.speedSetting == 1) {
    gamespeed = 18;  //22;
  } else if (clockConfig.speedSetting == 2) {
    gamespeed = 12;  //14;
  } else if (clockConfig.speedSetting == 3) {
    gamespeed = 0;
  }
  dly = gamespeed; // Reset the game speed
}

////////////////////////////////////////////////////////////
//
//
//
void printscoreboard() { //Print scoreboard

  if ((ghostscore >= 95) || (pacmanscore >= 95)) { // Reset scoreboard if over 95
    ghostscore = 0;
    pacmanscore = 0;
    for (int dotarray = 1; dotarray < 73; dotarray++) {

      dots[dotarray].state = true;
    }

    // Blank the screen across the digits before redrawing them
    //  myGLCD.setColor(0, 0, 0);
    //  myGLCD.setBackColor(0, 0, 0);

    myGLCD.fillRect(299  , 87  , 15  , 10  , TFT_BLACK); // Blankout ghost score
    myGLCD.fillRect(7  , 87  , 15  , 10  , TFT_BLACK);   // Blankout pacman score

    drawscreen(); // Redraw dots
  }

  myGLCD.setTextColor(TFT_RED, TFT_BLACK);
  myGLCD.setTextSize(1);

  // Account for position issue if over or under 10

  if (ghostscore >= 10) {
    //  myGLCD.setColor(237, 28, 36);
    //  myGLCD.setBackColor(0, 0, 0);
    myGLCD.drawNumber(ghostscore, 301, 88);
  } else {
    //  myGLCD.setColor(237, 28, 36);
    //  myGLCD.setBackColor(0, 0, 0);
    myGLCD.drawNumber(ghostscore, 307, 88); // Account for being less than 10
  }

  myGLCD.setTextColor(TFT_YELLOW, TFT_BLACK);   myGLCD.setTextSize(1);

  if (pacmanscore >= 10) {
    //  myGLCD.setColor(248, 236, 1);
    //  myGLCD.setBackColor(0, 0, 0);
    myGLCD.drawNumber(pacmanscore, 9, 88);
  } else {
    //  myGLCD.setColor(248, 236, 1);
    //  myGLCD.setBackColor(0, 0, 0);
    myGLCD.drawNumber(pacmanscore, 15, 88); // Account for being less than 10
  }
}

///////////////////////////////////////////////////////////
//
//
//
void drawfruit() { // Draw fruit and allocate points

  // Draw fruit
  if ((fruitdrawn == false) && (fruitgone == false)) { // draw fruit and set flag that fruit present so its not drawn again
    //drawicon(146, 168, fruit); //   draw fruit
    myGLCD.pushImage(146, 168, 28, 28, fruitIcon);
    fruitdrawn = true;
  }

  // Redraw fruit if Ghost eats fruit only if Ghost passesover 172 or 120 on the row 186
  if ((fruitdrawn == true) && (fruitgone == false) && (xG >= 168) && (xG <= 170) && (yG >= 168) && (yG <= 180)) {
    //drawicon(146, 168, fruit); //   draw fruit
    myGLCD.pushImage(146, 168, 28, 28, fruitIcon);
  }

  if ((fruitdrawn == true) && (fruitgone == false) && (xG == 120) && (yG == 168)) {
    //drawicon(146, 168, fruit); //   draw fruit
    myGLCD.pushImage(146, 168, 28, 28, fruitIcon);
  }

  // Award Points if Pacman eats Big Dots
  if ((fruitdrawn == true) && (fruitgone == false) && (xP == 146) && (yP == 168)) {
    fruitgone = true; // If Pacman eats fruit then fruit disappears
    pacmanscore = pacmanscore + 5; //Increment pacman score
  }
}

///////////////////////////////////////////////////////////
//
//  Read the current date and time from the RTC and
//      reset the game board.
//
void refreshgame()
{
  // Read the current date and time from the RTC and reset board
#ifdef DS3231_RTC
  if (!digitalRead(RTC_INT_PIN))   // RTC interrupt
  {
    //
    //  RTC alarm #2 interrupt (occurs once a minute)
    //
    if (rtc.alarmFired(ALARM_2))  // clear RTC alarm #2 interrupt (occurs once a minute)
    {
      rtc.clearAlarm(ALARM_2);
      UpdateDisp(); // update value to clock then ...
      fruiteatenpacman =  false; // Turn Ghost red again
      fruitdrawn = false; // If Pacman eats fruit then fruit disappears
      fruitgone = false;
      // Reset every minute both characters
      pacmanlost = false;
      ghostlost = false;
      dly = gamespeed; // reset delay
      rfc = 0;
    }
  }
#else
  rfc++;
  if (rfc >= rfcvalue) { // count cycles and print time
    UpdateDisp(); // update value to clock then ...
    fruiteatenpacman =  false; // Turn Ghost red again
    fruitdrawn = false; // If Pacman eats fruit then fruit disappears
    fruitgone = false;
    // Reset every minute both characters
    pacmanlost = false;
    ghostlost = false;
    dly = gamespeed; // reset delay
    rfc = 0;
  }
#endif
}

///////////////////////////////////////////////////////////
//
//  Check to determine if the Alarm needs to be sounded
//
void triggeralarm()
{
  if (clockConfig.alarmStatus == true) {

    if ( (clockConfig.alarmHour == clockhour) && (clockConfig.alarmMinute == clockminute)) {  // Sound the alarm
      soundalarm = true;
    }

  }
}

/////////////////////////////////////////////////////////////
//
// Check if user input to touch screen
//    UserT sets direction 0 = right, 1 = down, 2 = left, 3 = up, 4 = no touch input
//    Read the Touch Screen Locations
//
//
void mainuserinput()
{
  pushTA();
#ifdef TFT_SPI
  if (touchCheck())
  {
    // If centre of screen touched while alarm sounding then turn off the sound and reset the alarm to not set
    //    if ((touchData.y >= 90) && (touchData.y <= 150))
    //    {
    //      if ((touchData.x >= 130) && (touchData.x <= 190))
    if ((touchData.button == 5) || (touchData.button == 8))   // middle of row 2 & 3
    {
      if (soundalarm == true)
      {
        clockConfig.alarmStatus = false;
        soundalarm = false;
        delay(250);
      }
      else
      {
        // **********************************
        // ******* Enter Setup Mode *********
        // **********************************
        PACMAN_PRINTLN(F("Entering Setup"));
        setupclockmenu();
      }
    }
    //    }
    if (pacmanlost == false)
    {
      TOUCH_PRINTLN("Direction Change");
      switch (touchData.button)
      {
        case 2:   // Request to go UP
          if ( D == 1)
          {
            TOUCH_PRINTLN(F("Go up"));
            D = 3;
          }
          break;
        case 4:   // Request to go LEFT
        case 7:
          if ( D == 0)
          {
            TOUCH_PRINTLN(F("Go left"));
            D = 2;
          }
          break;
        case 6:   // Request to go RIGHT
        case 9:
          if ( D == 2)
          {
            TOUCH_PRINTLN(F("Go right"));
            D = 0;
          }
          break;
        case 8:   // Request to go DOWN
          if (D == 3)
          {
            TOUCH_PRINTLN(F("Go down"));
            D = 1;
          }
          break;
        default:
          break;
      }
    }
    touchData.touchedFlag = false;
    delay(200);
  }
  //=== Start Alarm Sound - Sound pays for 10 seconds then will restart at 20 second mark

  if ((clockConfig.alarmStatus == true) && (soundalarm == true)) { // Set off a counter and take action to restart sound if screen not touched

    playalarmsound1();
    UpdateDisp(); // update value to clock
  }
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

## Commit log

2022-11-15 Add files via upload
    Add clock case 3D models.
    [BezelDecal.stl, BezelTrim.stl, ClockBezel.stl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]
2023-02-21 Adding PCB bill of materials
    [PCB_BOM.xlsx]
